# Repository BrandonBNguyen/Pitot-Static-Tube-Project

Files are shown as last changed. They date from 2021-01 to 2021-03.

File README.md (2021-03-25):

# 3D Printed Pitot Static Tube Project

## Introduction

The goal of this project was to design and develop an instrument capable of acquiring accurate measurements of air speed.

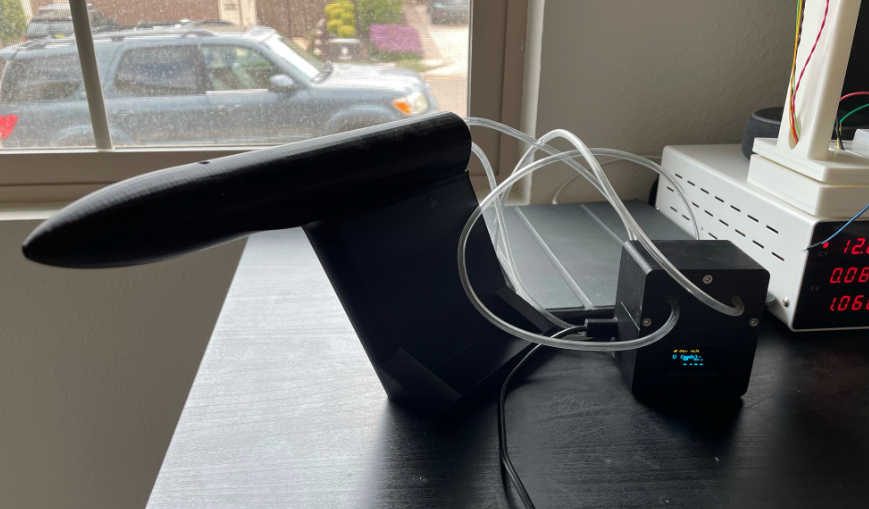
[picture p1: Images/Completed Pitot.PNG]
Completed Pitot Sensor Assembly


## To Do List

 - [x] Select and order components
	 - [x] Pressure sensors ([BMP180](https://www.amazon.com/gp/product/B07Q3PQ81R/ref=ppx_yo_dt_b_search_asin_title?ie=UTF8&psc=1))
	 - [x] Display ([UCTRONICS 0.96 Inch OLED Module](https://www.amazon.com/gp/product/B072Q2X2LL/ref=ppx_yo_dt_b_asin_title_o01_s00?ie=UTF8&psc=1))
	 - [x] Microcontroller ([Teensy LC Board](https://www.pjrc.com/teensy/teensyLC.html))
	 - [x] Nozzle-to-sensor tubing ([4 mm OD pneumatic hose](https://www.amazon.com/gp/product/B07H87S1ZW/ref=ppx_yo_dt_b_asin_title_o06_s00?ie=UTF8&psc=1))
	 - [x] Power source (USB A to microUSB cable)
 - [x] Develop CAD Model
	 - [x] Pitot static tube nozzle assembly
	 - [x] Housing assembly for microcontroller and pressure sensors
 - [x] Test Electronics
	 - [x] Get pressure readings from single BMP 180
	 - [x] Get pressure readings from both BMP 180 sensors simultaneously.
	 - [x] Display pressure measurements and air speed reading to OLED display.
 - [x] Manufacture Components
	 - [x] 3D print nozzle assembly
	 - [x] 3D print housing assembly
	 - [x] Fasten microcontroller, pressure sensors, and OLED display to housing.
	 - [x] Solder and connect wiring.
	 - [x] Connect tubing from nozzle assembly to housing assembly.
	 - [x] Apply sealant to joints and openings in chamber housing pressure sensors.
 - [x] Test and Validate

## Theory

A pitot static tube is an instrument that measures air speed by measuring the pressure at an opening facing directly into the air flow (stagnation pressure), measuring the pressure at an opening perpendicular to the air flow (static pressure), and using the difference in pressure between the two to calculate air speed via Bernoulli's equation.

Pitot-Static Tube

The pitot static tube will be tested to measure air speed from a moving car. The density used in the Bernoulli equation from the above diagram will be calculated from pressure and temperature measurements taken from a stationary position.

## Part Selection

### Sensor Selection

The BMP180 barometric pressure and temperature sensor module was selected to record the differences in pressure between the stagnation pressure and static pressure.

BMP180 Sensors

With a resolution up to 0.03 hPa (3 Pa), the anticipated accuracy of using this sensor to measure air speed is within 2.2 m/s (4.9 mph).

Sensor Accuracy Equation

### Microcontroller Selection

Initial tests to acquire measurements from both BMP180 sensors using an Arduino Uno were unsuccessful due to the sensors sharing the same I2C address. The ability to measure from both sensors and thus record a pressure difference between stagnation and static pressure would require either the use of a multiplexer or a microcontroller with multiple I2C buses. To reduce the number of components used, saving on space and work required to assemble, the latter solution was chosen and the Teensy LC microcontroller board was selected.

### Display

To display the recorded pressure difference and resulting air speed measured from the pitot static tube, the UCTRONICS OLED Module 12864 was selected.

UCTRONICS OLED Module 12864

## CAD Model

### Nozzle Assembly

The nozzle assembly is designed to be clamped to the roof or out of the window of a car and consists of two parts: the main nozzle and the support.

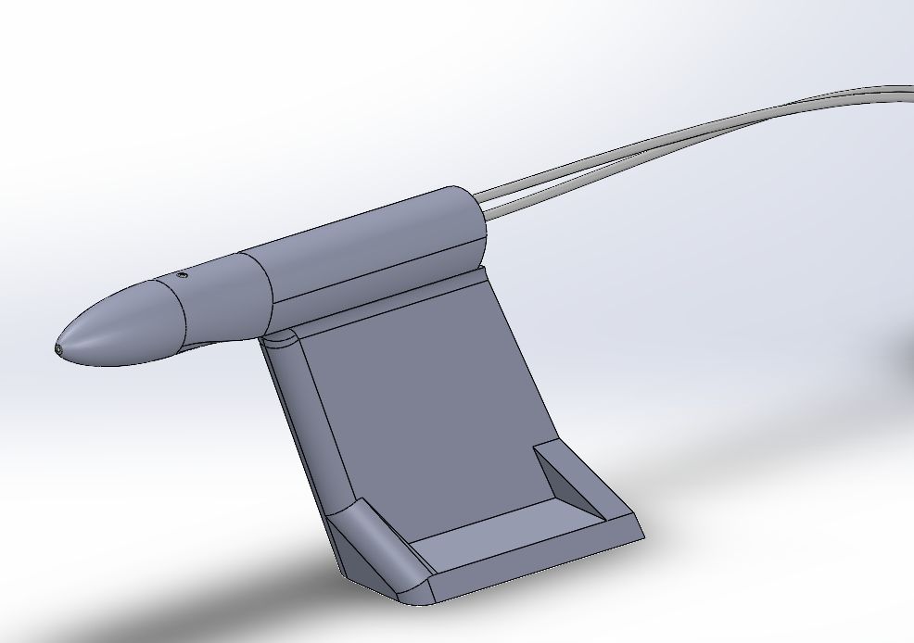
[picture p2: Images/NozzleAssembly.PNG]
Nozzle Assembly


*Nozzle assembly featuring tubing running to pressure sensor chambers.*

#### Nozzle

The main nozzle has a hole in the front which will be connected to a pressure sensor chamber to measure stagnation pressure, and has a hole on the top which will be connected to a separate pressure sensor chamber to measure static pressure. The underside of the nozzle features a dovetail cutout for a rail from the support to be slotted into.

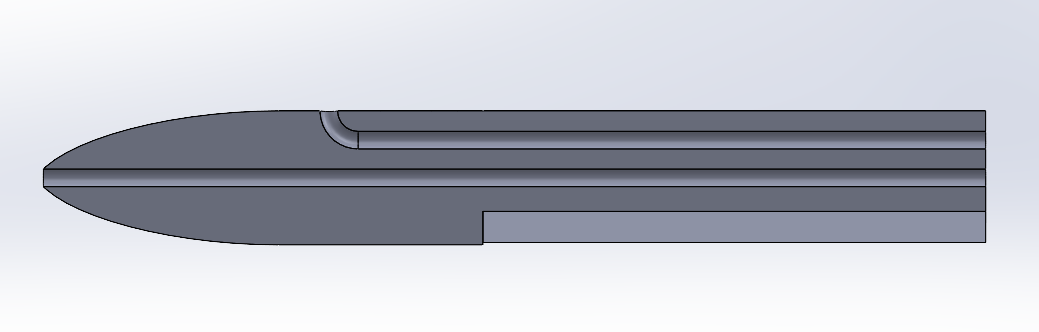
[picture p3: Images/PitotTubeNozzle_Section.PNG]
Section View


*Section view of the nozzle showing internal paths to the front and top of the nozzle to measure stagnation pressure and static pressure, respectively.*

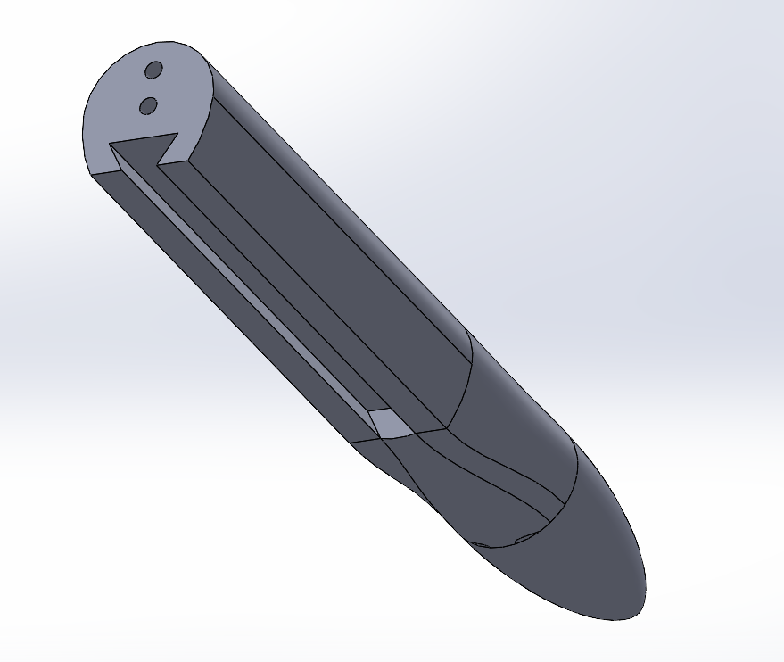
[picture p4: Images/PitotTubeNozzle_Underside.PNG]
Underside View


*Underside view of the nozzle showing the dovetail slot to connect to the support.*

#### Support

The support features a dovetail at one end and a flat edge on the other for which to connect a clamp to hold the entire assembly in place. The support is designed in this way to place the nozzle far out in front and away from the vehicle to ensure that the instrument is not measuring reduced air speeds due to air being slowed by the boundary layer of the vehicle.

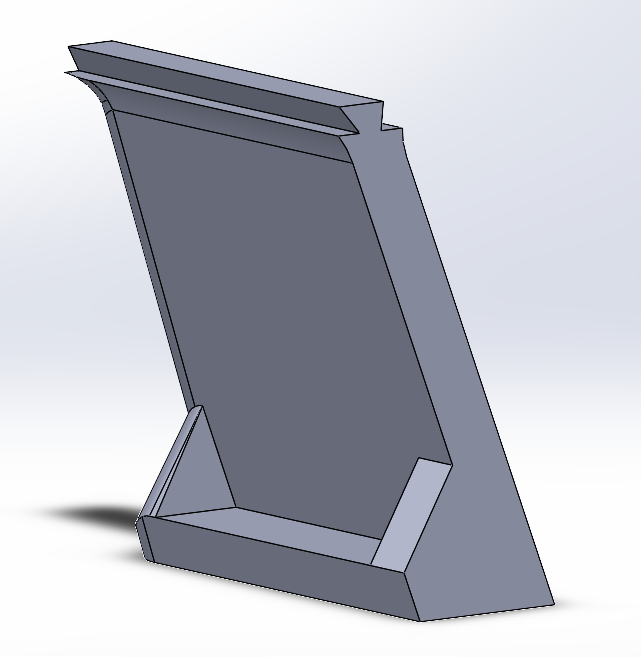
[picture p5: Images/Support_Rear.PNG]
Support rear view


*Rear view of the support showing the dovetail rail on top and the flat edge on the bottom to be clamped.*

### Sensor and Board Housing

#### Initial Design

This initial design for the sensor and board housing was designed for using an Arduino Uno to measure and record readings from the BMP180 sensors and display them via serial output to a computer. Each BMP180 sensor would be housed in its own chamber with wiring passing through a wall between the chamber and the compartment holding the Arduino Uno. A lid with a hole for tubing to each chamber would be fastened to enclose the pressure sensor chambers. Silicone sealant would be used on the wall holding the wiring and between the lid and the housing to ensure an air tight seal for accurate pressure measurements from the two points on the nozzle.

 The CAD design for this was created before tests showed that the Arduino Uno would not be suitable for measuring from both sensors simultaneously. **Lesson learned: ensure that all electronic components work together as expected before designing custom parts for those components.** 

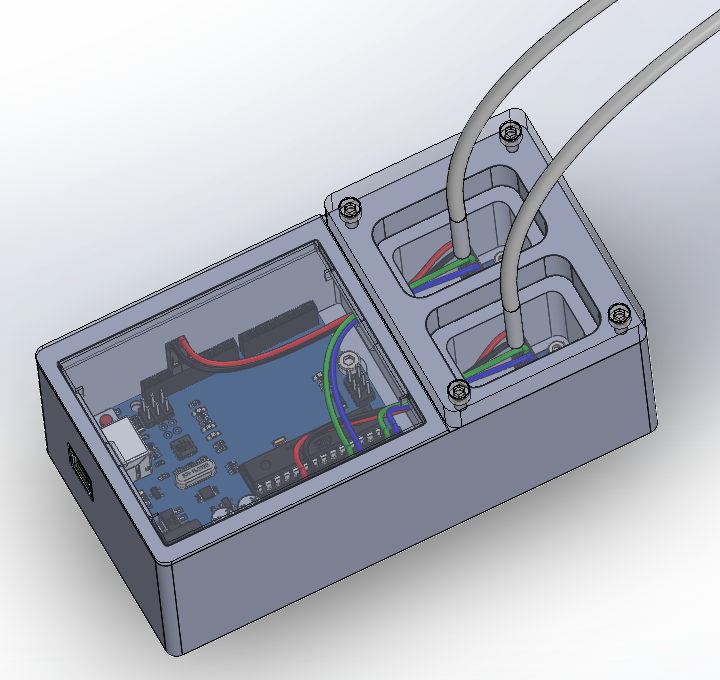
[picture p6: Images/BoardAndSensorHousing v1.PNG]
Initial Board and Sensor Housing Design


#### Final Design

The final design features the Teensy LC microcontroller on one side of the housing and the two BMP180 pressure sensors, each in their own housing, on the other side. The lid to cover the microcontroller is embedded with the outward facing OLED display to show the calculated airspeed result from the pressure difference.

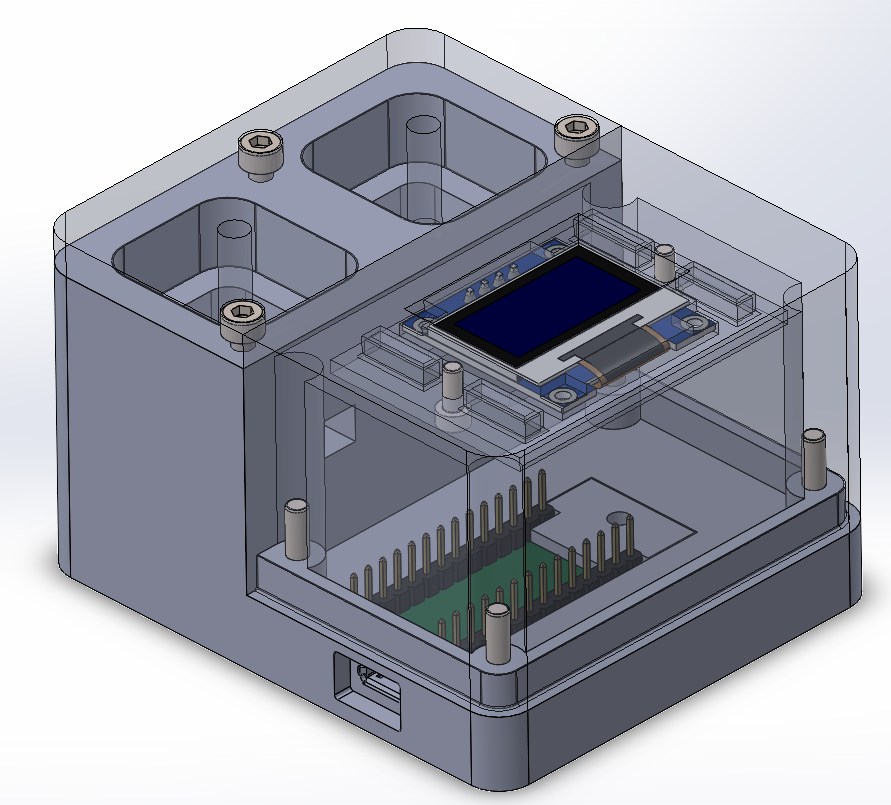
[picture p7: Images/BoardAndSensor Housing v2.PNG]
Final Board and Sensor Housing Design


## Manufacturing

### Nozzle Assembly

The nozzle was printed using black PLA at 210°C with a bed temperature of 60°C. The first attempt at printing the nozzle failed when the print became separated from the build plate. This was likely due to the nozzle being a tall, thin structure with little surface area on the first layer to hold the print in place. The movement of the build plate back and forth along the Y axis and/or friction between nozzle and part likely induced stress on the first layer that lead to separation.

Failed nozzle print attempt

The second attempt at printing the nozzle was printed with a raft, greatly increasing the surface area between the part and the build plate and reducing stresses on the first layer due to movement or friction with the nozzle. This resulted in a successful print.

The nozzle support was printed successfully on the first attempt. The rail fit onto the slot in the nozzle with a snug fit.

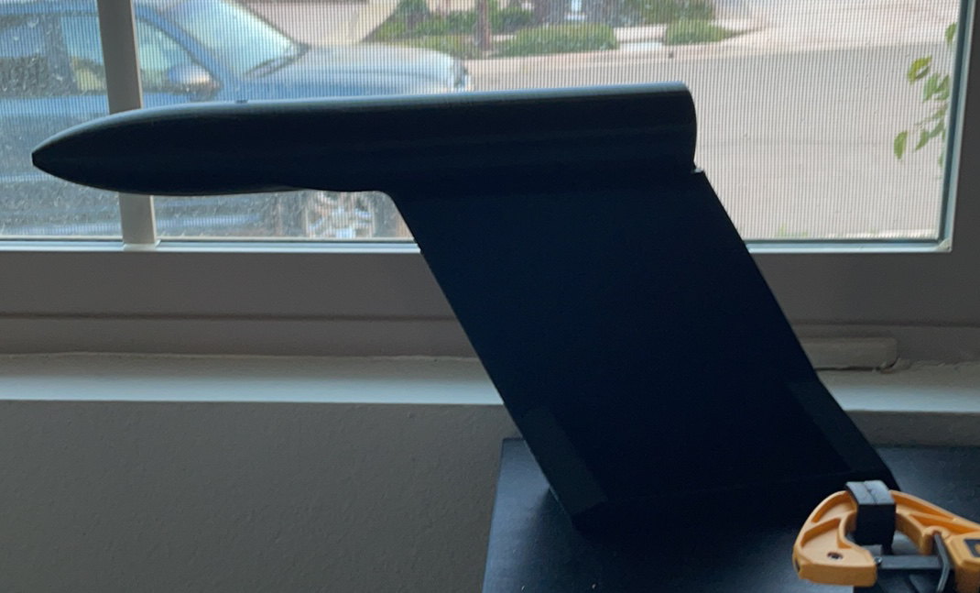
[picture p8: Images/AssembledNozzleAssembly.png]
Printed nozzle assembly


## Testing and Technical Challenges

### Shared I2C Address

A major technical problem that arose while testing the sensors was the fact that the sensors share the same I2C address. An attempted solution involved using the Arduino Uno's hardware I2C bus to measure the result from one sensor and a software I2C bus to measure the result from the other, although implementation of this solution was unsuccessful. Another solution considered was using a multiplexer to facilitate the communication between the Arduino and devices sharing I2C addresses, although this would require additional space in the housing for another component. The solution reached was to use a microcontroller that has two I2C buses such that each sensor would be on a separate I2C bus.

### Measuring from 2 BMP180 Sensors

The [SparkFun BMP180](https://github.com/sparkfun/BMP180_Breakout_Arduino_Library) library was designed to read the pressure and temperature from a single BMP180 sensor on the default I2C bus. To measure the pressure from 2 BMP180 sensors, one on the default I2C bus and the other on the second, the library had to be modified to use the `i2c_t3.h` library instead of the `Wire.h` library. Then, that library was duplicated and modified to use `Wire1` instead of `Wire` to access the BMP180 sensor on the second I2C bus. One library with the original `Wire` was used to measure the pressure from the sensor on the default I2C bus and the other with `Wire1` was used to measure the sensor on the secondary I2C bus.

### Integrating SSD1306 OLED Panel

The [Adafruit SSD1306 library](https://github.com/adafruit/Adafruit_SSD1306), [GFX library](https://github.com/adafruit/Adafruit-GFX-Library), and [BusIO library](https://github.com/adafruit/Adafruit_BusIO) were used to display text and readings to the OLED display. Since the `i2c_t3.h` library was being used to measure the pressure from the sensors, `Wire.h` could not be used to display text and readings and the above libraries had to be changed to use the `i2c_t3.h` library instead of `Wire.h`. Additionally, all instances of `TwoWire` had to be changed to `i2c_t3`.

Successful test showing calculated airspeed displayed on panel from pressure sensors.

## Attributes

The links to the pre-made models used in the CAD made for this project are linked below.

 - [BMP180 Board](https://grabcad.com/library/bmp180-3) by Karolina Seth
 - [Arduino Uno R3 Board](https://grabcad.com/library/arduino-uno-r3-1) by Andrew Whitham
 - [Teensy LC Board](https://grabcad.com/library/teensy-lc-1) by Aron Rubin
 - [SSD1306 OLED Display](https://grabcad.com/library/display-oled-ssd1306-de-0-96-1) by UNIT ELECTRONICS

## Skills Demonstrated

 - Demonstrated strong computer-aided design skills using SolidWorks in working with multiple parts in assemblies and designing custom parts for electronic components.
 - Demonstrated ability to troubleshoot.
	 - Identified cause for failure of a part to print successfully and implemented  solution to increase build plate adhesion.
	 - Identified issue with measuring from multiple sensors that share the same I2C address and identified multiple solutions before implementing the best one.
 - Demonstrated knowledge of C++ and applied it to use a microcontroller to read sensor data and display information using I2C protocol.

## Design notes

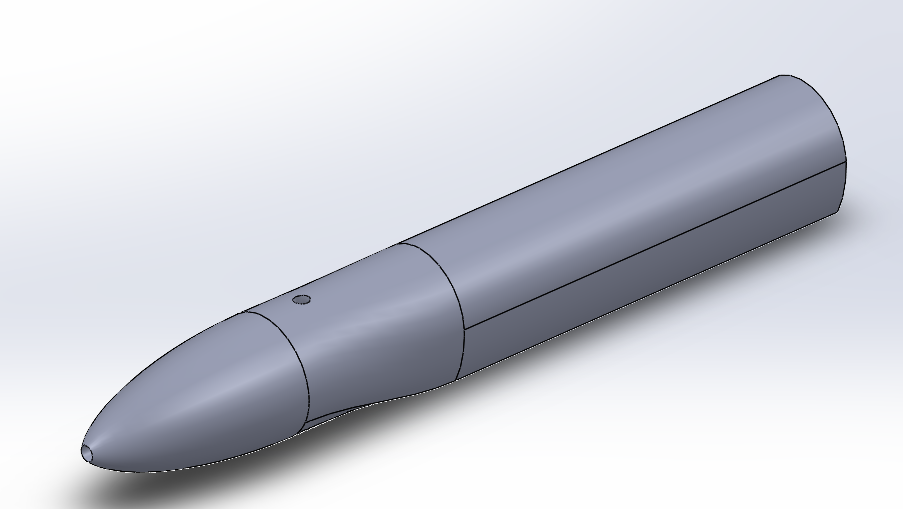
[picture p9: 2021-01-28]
Images/PitotTubeNozzle_Angled.PNG

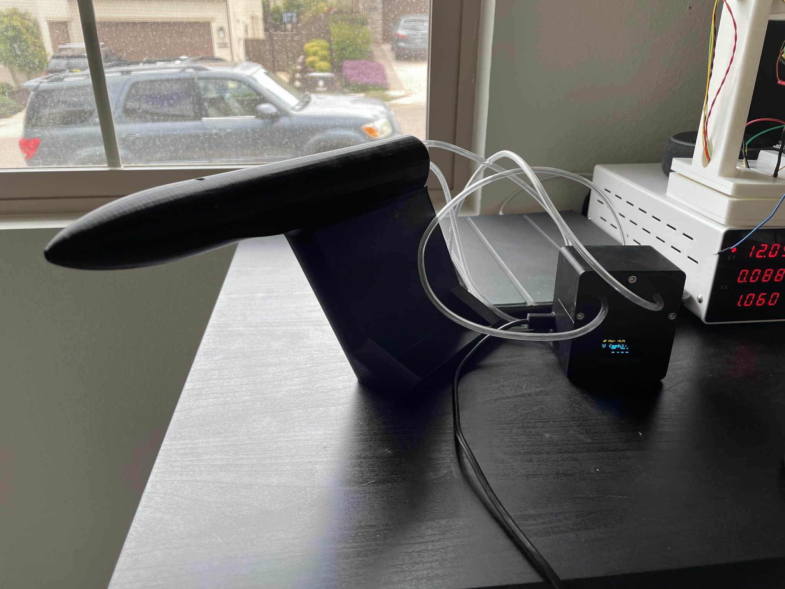
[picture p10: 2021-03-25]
Images/Completed Pitot.jpeg

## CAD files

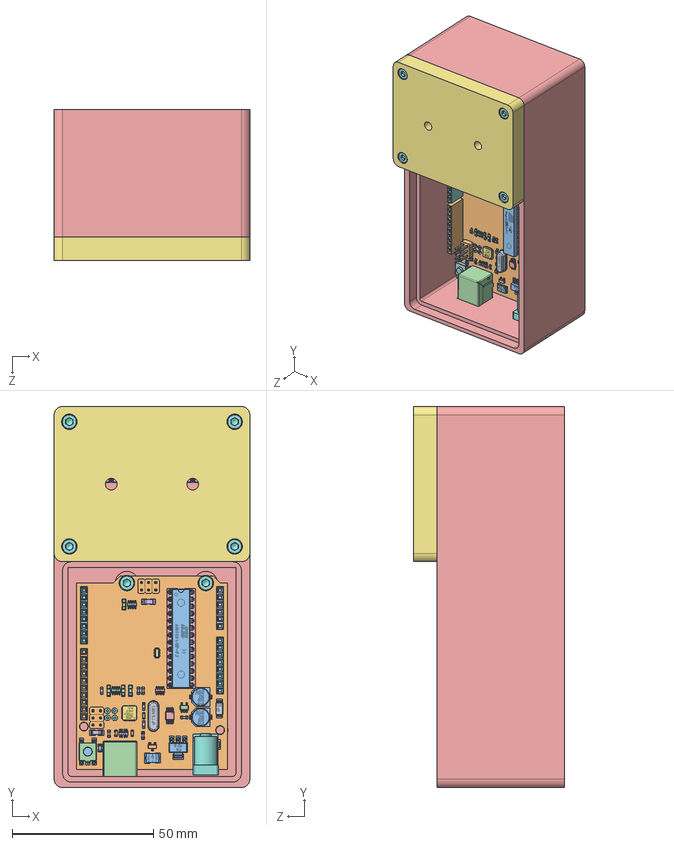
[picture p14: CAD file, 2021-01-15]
Arduino Uno R3 Model/Pressure Sensor Housing.SLDASM
69.3 x 134.9 x 53.3 mm
bmp180 x 2
unoboard blue
47uf CAP Dcase x 2
USB SHELL
USB core
usb top contact x 2
usb btm contact x 2
power jack
crystal
2pin_header__02 x 6
nano - reg
led x 4
dip28
dip socket pin x 28
atmega16u2
8 PORT HEADER x 2
6 PORT HEADER
10 PORT HEADER
ATMEL328P
102 RESISTOR PACK x 2
103 RESISTOR PACK
220 RESISTOR PACK
16mhz crystal - measured
PADS001
603 cap on pad x 8
ssot3
mf-msmf050-2
lmv358
lp2985dgkr
cd1206 diode x 2
603 resistor
blm21
m7 diode
MLC0603 x 2
RESET CORE
RESET
Part7^Pressure Sensor Housing
Pin Connector x 8
Part1^Pressure Sensor Housing
socket head cap screw_am x 8

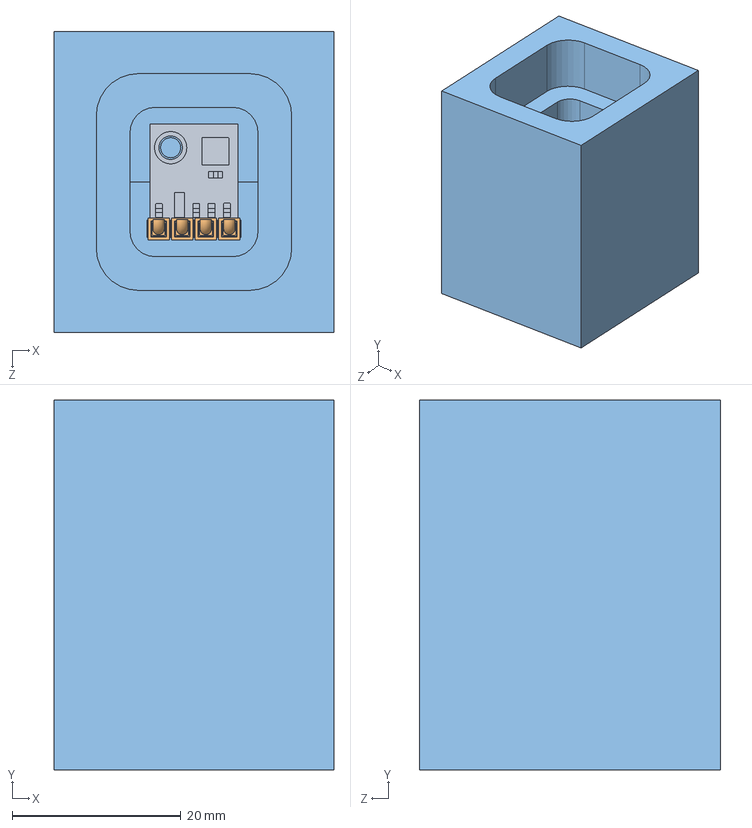
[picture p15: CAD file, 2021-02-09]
CAD/BMP180 Housing.SLDASM
33.2 x 43.9 x 35.7 mm
bmp180
Pin Connector x 4
Part2^BMP180 Housing

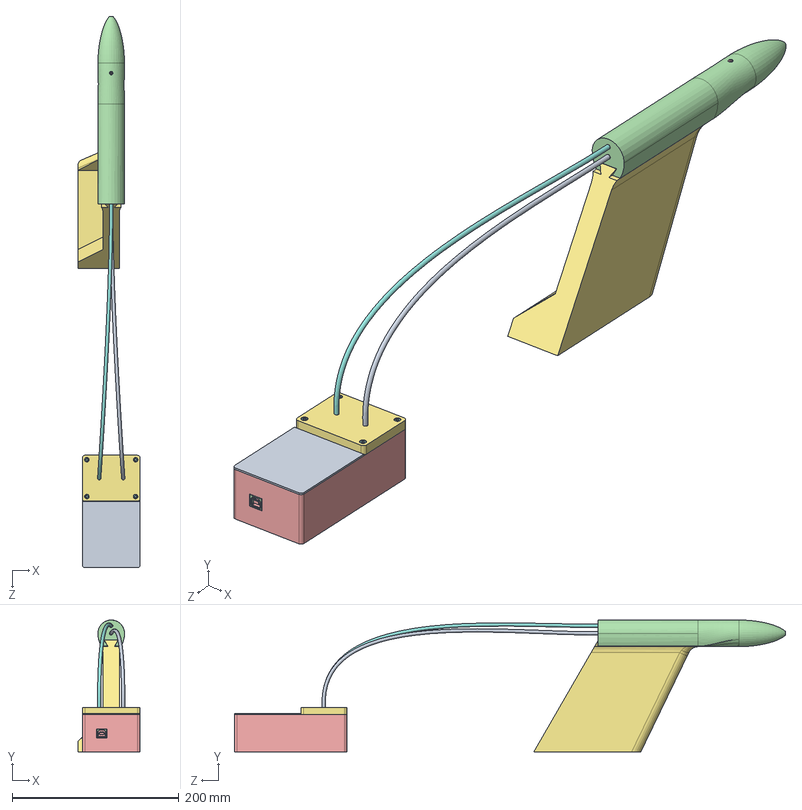
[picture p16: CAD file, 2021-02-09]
CAD/Version 1/01 Pitot Static Tube Full Assembly.SLDASM
74.7 x 158.4 x 661.6 mm
bmp180 x 2
unoboard blue
47uf CAP Dcase x 2
USB SHELL
USB core
usb top contact x 2
usb btm contact x 2
power jack
crystal
2pin_header__02 x 6
nano - reg
led x 4
dip28
dip socket pin x 28
atmega16u2
8 PORT HEADER x 2
6 PORT HEADER
10 PORT HEADER
ATMEL328P
102 RESISTOR PACK x 2
103 RESISTOR PACK
220 RESISTOR PACK
16mhz crystal - measured
PADS001
603 cap on pad x 8
ssot3
mf-msmf050-2
lmv358
lp2985dgkr
cd1206 diode x 2
603 resistor
blm21
m7 diode
MLC0603 x 2
RESET CORE
RESET
Pressure Sensor Housing
Pin Connector x 8
Part1^Pressure Sensor Housing
socket head cap screw_am x 8
Part2^Pressure Sensor Housing
Pin Connector Male x 8
Part3^Pressure Sensor Housing
Part5^Pressure Sensor Housing
Part6^Pressure Sensor Housing
Part8^Pressure Sensor Housing
Part9^Pressure Sensor Housing
Part10^Pressure Sensor Housing
Part11^Pressure Sensor Housing
Part12^Pressure Sensor Housing
Part4^Pressure Sensor Housing
Nozzle^Pitot Nozzle Assembly
Static Pressure Tube^Pitot Nozzle Assembly
Stagnation Pressure Tube^Pitot Nozzle Assembly
Nozzle Mount^Pitot Nozzle Assembly
Part6^01 Pitot Static Tube Full Assembly
Part7^01 Pitot Static Tube Full Assembly

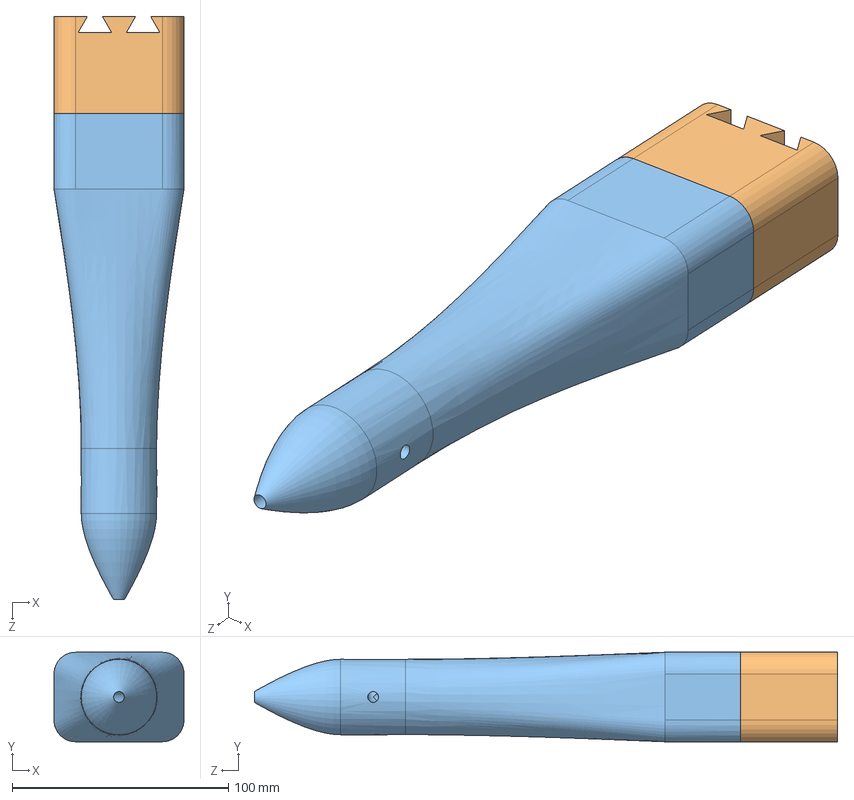
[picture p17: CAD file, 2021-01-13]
Pitot Static Tube.SLDASM
60.2 x 41.4 x 270.0 mm
bmp180 x 2
Part2^Pitot Static Tube
Part3^Pitot Static Tube
Pin Connector

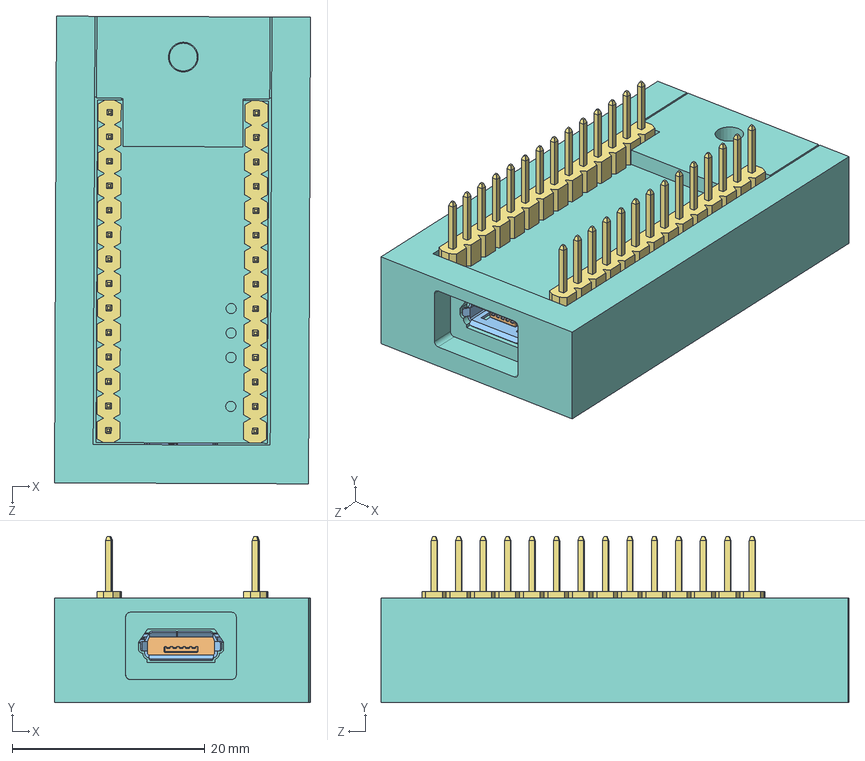
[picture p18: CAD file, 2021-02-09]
CAD/Teensy LC Housing.SLDASM
26.6 x 17.3 x 48.6 mm
Group#12 (1).stp x 5
micro_usb_plastic (1).stp
micro_usb_shell (1).stp
Component21.stp
lead.stp
Component38.stp
Component39.stp
Component40.stp
Component41.stp
Component43.stp
Component44.stp
Component45.stp
Component46.stp
package.stp
lead (1).stp
board.stp
diode_0402 v1.stp x 4
cap0603_03 v3.stp x 2
qfn48 v2.stp
cap0402 v2.stp x 6
resistor_0805 v2.stp
smt_led_0603 v2.stp
Teensy Pin Headers^Teensy LC Housing

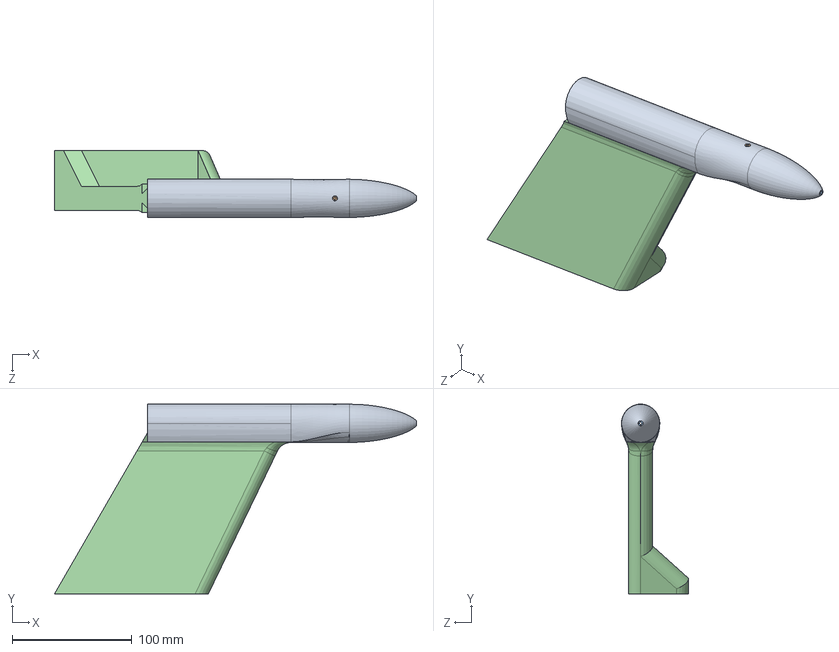
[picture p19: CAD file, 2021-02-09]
CAD/02 Pitot Nozzle Assembly.SLDASM
302.4 x 158.4 x 56.0 mm
Nozzle^Pitot Nozzle Assembly
Static Pressure Tube^Pitot Nozzle Assembly
Stagnation Pressure Tube^Pitot Nozzle Assembly
Nozzle Mount^Pitot Nozzle Assembly

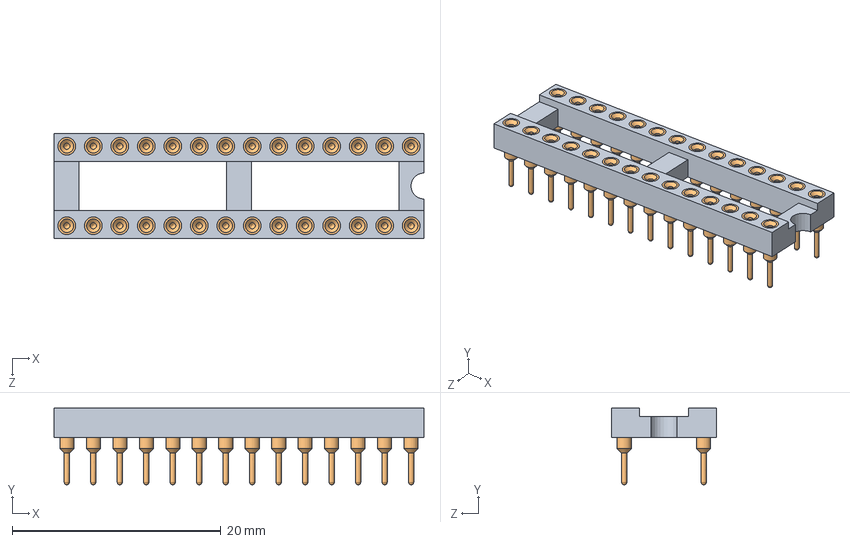
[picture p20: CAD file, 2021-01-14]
CAD/Arduino Uno R3 Model/dip28.SLDASM
35.5 x 7.37 x 10.1 mm
dip28
dip socket pin x 28

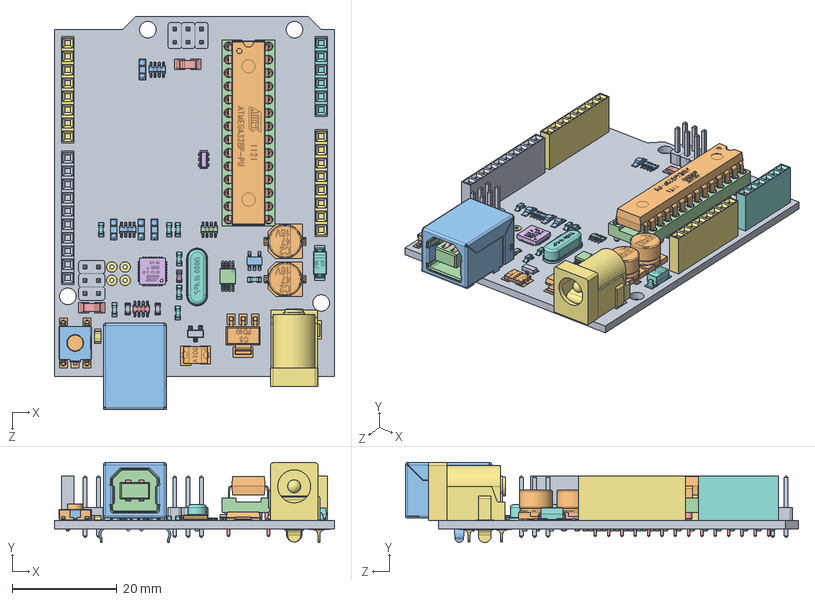
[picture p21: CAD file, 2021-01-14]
CAD/Arduino Uno R3 Model/arduino uno.SLDASM
53.3 x 15.2 x 74.9 mm
unoboard blue
47uf CAP Dcase x 2
USB SHELL
USB core
usb top contact x 2
usb btm contact x 2
power jack
crystal
2pin_header__02 x 6
nano - reg
led x 4
dip28
dip socket pin x 28
atmega16u2
8 PORT HEADER x 2
6 PORT HEADER
10 PORT HEADER
ATMEL328P
102 RESISTOR PACK x 2
103 RESISTOR PACK
220 RESISTOR PACK
16mhz crystal - measured
PADS001
603 cap on pad x 8
ssot3
mf-msmf050-2
lmv358
lp2985dgkr
cd1206 diode x 2
603 resistor
blm21
m7 diode
MLC0603 x 2
RESET CORE
RESET

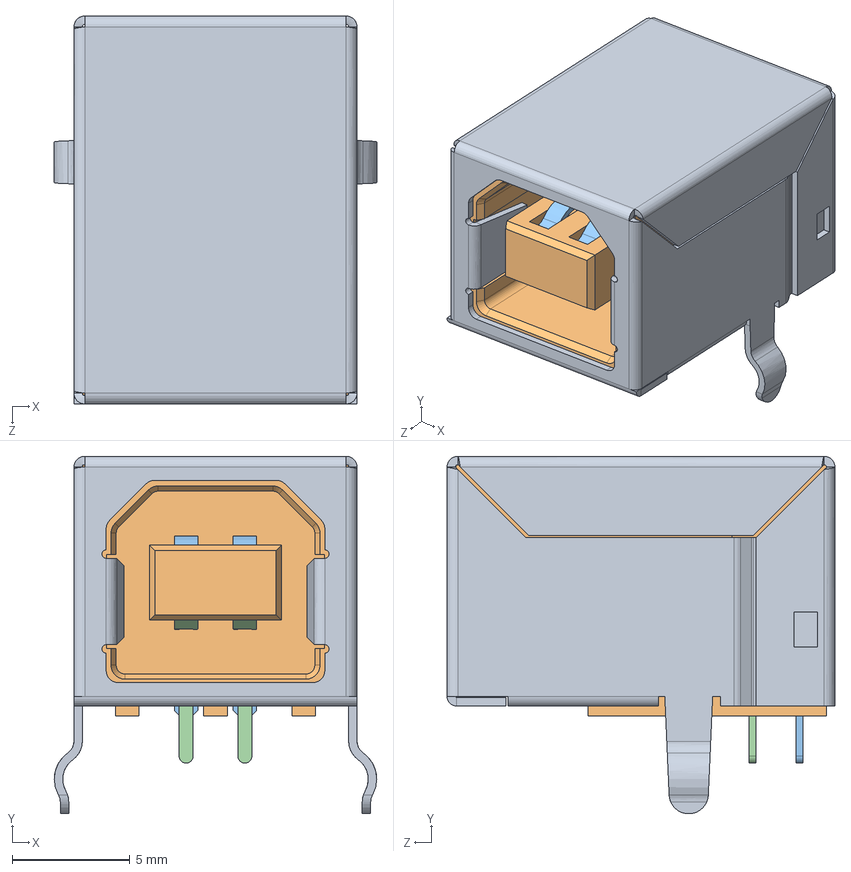
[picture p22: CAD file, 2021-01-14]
CAD/Arduino Uno R3 Model/USB type b.SLDPRT.SLDASM
13.7 x 15.2 x 16.5 mm
USB SHELL
USB core
usb top contact x 2
usb btm contact x 2

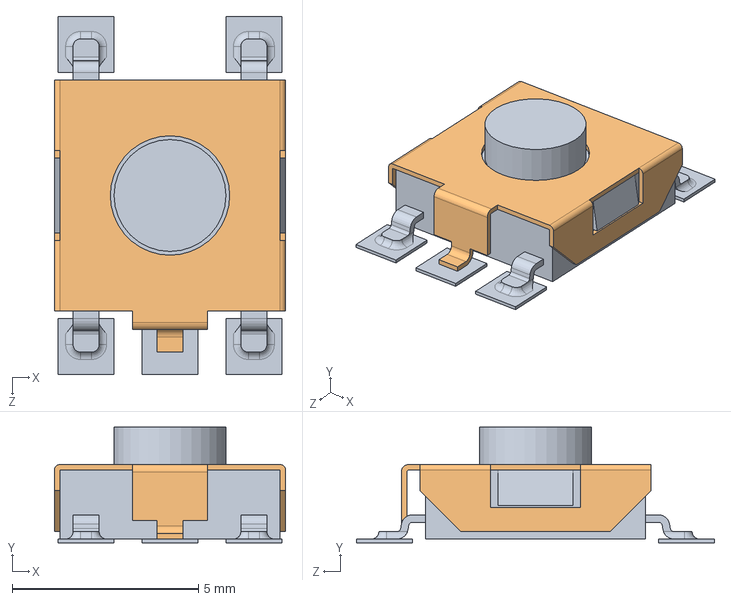
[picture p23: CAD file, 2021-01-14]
CAD/Arduino Uno R3 Model/RESET BUTTON.SLDASM
6.20 x 3.10 x 9.60 mm
RESET CORE
RESET

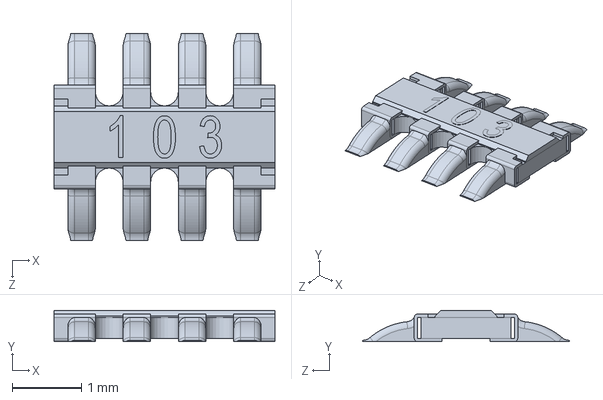
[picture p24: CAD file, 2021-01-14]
CAD/Arduino Uno R3 Model/103 RESISTOR PACK.SLDPRT
3.20 x 0.455 x 3.00 mm

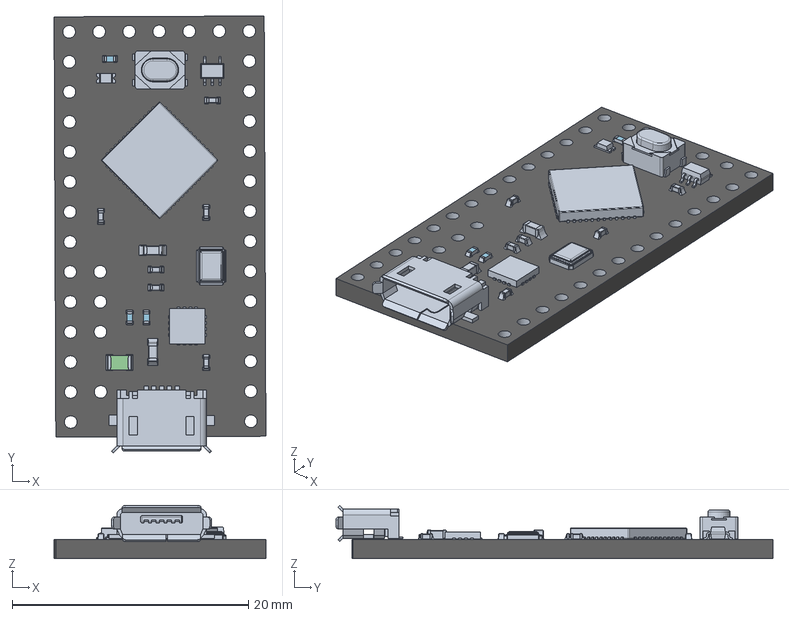
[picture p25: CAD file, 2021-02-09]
CAD/Teensy LC Model/Teensy_lc.stp
17.9 x 37.0 x 4.49 mm
board
micro_usb_plastic (1)
micro_usb_shell (1)
lead
diode_0402 v1 x 4
cap0603_03 v3 x 2
qfn48 v2
cap0402 v2 x 6
resistor_0805 v2
smt_led_0603 v2
package
lead (1)

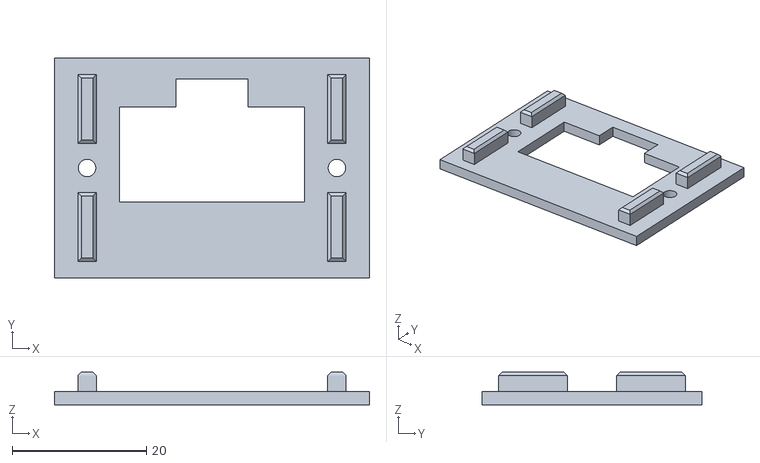
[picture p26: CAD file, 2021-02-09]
Print STL Files/OLED Panel Fastener.STL
46.9 x 32.8 x 4.90

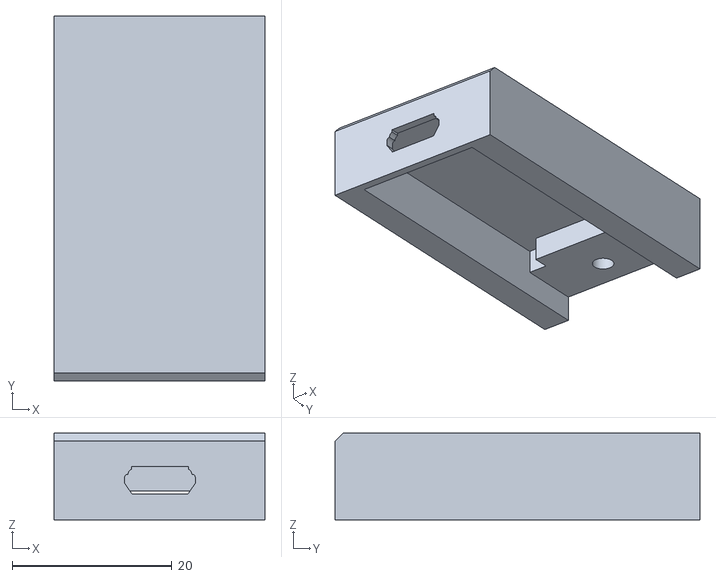
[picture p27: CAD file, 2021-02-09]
Test Prints/Teensy LC Housing.STL
26.4 x 45.7 x 10.9

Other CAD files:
CAD/Arduino Uno R3 Model/603 resistor.SLDPRT
CAD/Version 1/Pressure Sensor Housing.SLDPRT
Print STL Files/Pressure Sensor Housing Lid.STL
Test Prints/Teensy LC Lid.STL
CAD/Arduino Uno R3 Model/10 PORT HEADER.SLDPRT
CAD/Arduino Uno R3 Model/102 RESISTOR PACK.SLDPRT
CAD/Arduino Uno R3 Model/16mhz crystal - measured.SLDPRT
CAD/Arduino Uno R3 Model/220 RESISTOR PACK.SLDPRT
CAD/Arduino Uno R3 Model/2pin_header__02.sldprt
CAD/Arduino Uno R3 Model/47uf CAP Dcase.SLDPRT
CAD/Arduino Uno R3 Model/6 PORT HEADER.SLDPRT
CAD/Arduino Uno R3 Model/603 cap on pad.SLDPRT
CAD/Arduino Uno R3 Model/8 PORT HEADER.SLDPRT
CAD/Arduino Uno R3 Model/ATMEL328P.SLDPRT
CAD/Arduino Uno R3 Model/MLC0603.SLDPRT
CAD/Arduino Uno R3 Model/PADS001.SLDPRT
CAD/Arduino Uno R3 Model/RESET CORE.SLDPRT
CAD/Arduino Uno R3 Model/RESET.SLDPRT
CAD/Arduino Uno R3 Model/USB SHELL.SLDPRT
CAD/Arduino Uno R3 Model/USB core.SLDPRT
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

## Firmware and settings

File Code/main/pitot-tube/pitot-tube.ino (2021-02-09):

// Includes and definitions for SSD1306 Display.
#include <SPI.h>
#include <i2c_t3.h>
#include <Adafruit_GFX.h>
#include <Adafruit_SSD1306.h>

#define SCREEN_WIDTH 128 // OLED display width, in pixels
#define SCREEN_HEIGHT 64 // OLED display height, in pixels

// Declaration for an SSD1306 display connected to I2C (SDA, SCL pins)
// The pins for I2C are defined by the Wire-library. 
// On an arduino UNO:       A4(SDA), A5(SCL)
// On an arduino MEGA 2560: 20(SDA), 21(SCL)
// On an arduino LEONARDO:   2(SDA),  3(SCL), ...
#define OLED_RESET     4 // Reset pin # (or -1 if sharing Arduino reset pin)
#define SCREEN_ADDRESS 0x3C ///< See datasheet for Address; 0x3D for 128x64, 0x3C for 128x32
Adafruit_SSD1306 display(SCREEN_WIDTH, SCREEN_HEIGHT, &Wire, OLED_RESET);

#define NUMFLAKES     10 // Number of snowflakes in the animation example

#define LOGO_HEIGHT   16
#define LOGO_WIDTH    16
static const unsigned char PROGMEM logo_bmp[] =
{ B00000000, B11000000,
  B00000001, B11000000,
  B00000001, B11000000,
  B00000011, B11100000,
  B11110011, B11100000,
  B11111110, B11111000,
  B01111110, B11111111,
  B00110011, B10011111,
  B00011111, B11111100,
  B00001101, B01110000,
  B00011011, B10100000,
  B00111111, B11100000,
  B00111111, B11110000,
  B01111100, B11110000,
  B01110000, B01110000,
  B00000000, B00110000 };

// Includes and definitions for BMP180 sensors.
#include "sensor_read_functions.h"
SFE_BMP180 sensor_1;
SFE_BMP180_2 sensor_2;
float pressure_offset; // Accounts for offset in absolute pressure measurement between the two sensors.

void setup() {
  // Serial.begin(9600);
  // Serial.println("REBOOT");

  // SSD1306_SWITCHCAPVCC = generate display voltage from 3.3V internally
  if(!display.begin(SSD1306_SWITCHCAPVCC, SCREEN_ADDRESS)) {
    // Serial.println(F("SSD1306 allocation failed"));
    for(;;); // Don't proceed, loop forever
  }

  // Clear the buffer
  display.clearDisplay();
  display.setTextSize(1);      // Normal 1:1 pixel scale
  display.setTextColor(SSD1306_WHITE); // Draw white text
  display.setCursor(0, 0);     // Start at top-left corner
  display.cp437(true);         // Use full 256 char 'Code Page 437' font

  display.write("SSD1306 Initialized\n");
  display.display();

  if (sensor_1.begin())
  {
    // Serial.println("Sensor 1 init success");
    display.write("BMP180 1 Initialized\n");
    display.display();
  }
  else
  {
    // Sensor 1 failed to connect.
    // Serial.println("Sensor 1 init fail\n\n");
    display.write("BMP180 1 Initialized\n");
    display.display();
    while(1); // Pause forever.
  }

  if (sensor_2.begin())
  {
    // Serial.println("Sensor 2 init success");
    display.write("BMP180 2 Initialized\n");
    display.display();
  }
  else
  {
    // Sensor 2 failed to connect.
    // Serial.println("Sensor 2 init fail\n\n");
    display.write("BMP180 1 Initialized\n");
    display.display();
    while(1); // Pause forever.
  }

  // Measure the initial difference in pressure (assuming no airspeed) to get pressure sensor offset.
  pressure_offset = get_pressure(sensor_1) - get_pressure(sensor_2);
  display.write("Pressure Difference\nCalibrated");
  display.display();
}

void loop() {
  // Serial.print("Sensor 1 Pressure (mb): ");
  // Serial.println(get_pressure(sensor_1));
  // Serial.print("Sensor 2 Pressure (mb): ");
  // Serial.println(get_pressure(sensor_2));

  // Calculate difference in pressure in pascals.
  float diff_pressure = 100*(get_pressure(sensor_1) - (get_pressure(sensor_2) + pressure_offset));
  float airspeed = sqrt(2 * abs(diff_pressure) / 1.225);

  // Serial.print("Pressure Diff (Pa): ");
  // Serial.println(diff_pressure);
  // Serial.print("Calculated Airspeed (m/s): ");
  // Serial.println(airspeed);
  // Serial.print("Calculated Airspeed (mph): ");
  // Serial.println(airspeed * 2.23694);
  // Serial.println();

  display.clearDisplay();
  display.setCursor(0,0);
  display.print("dP (Pa): ");
  display.println(diff_pressure);
  display.println();
  display.setTextSize(2);
  display.println("V (mph): ");
  display.setTextSize(3);
  if (airspeed * 2.23694 <= 10) {
    display.print("  ");
  } else if (airspeed * 2.23694 <= 100) {
    display.print(" ");
  }
  display.println(airspeed * 2.23694);
  display.setTextSize(1);
  display.display();

  delay(10);
}

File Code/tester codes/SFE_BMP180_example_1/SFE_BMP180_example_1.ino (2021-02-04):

/* SFE_BMP180 library example sketch

This sketch shows how to use the SFE_BMP180 library to read the
Bosch BMP180 barometric pressure sensor.
https://www.sparkfun.com/products/11824

Like most pressure sensors, the BMP180 measures absolute pressure.
This is the actual ambient pressure seen by the device, which will
vary with both altitude and weather.

Before taking a pressure reading you must take a temparture reading.
This is done with startTemperature() and getTemperature().
The result is in degrees C.

Once you have a temperature reading, you can take a pressure reading.
This is done with startPressure() and getPressure().
The result is in millibar (mb) aka hectopascals (hPa).

If you'll be monitoring weather patterns, you will probably want to
remove the effects of altitude. This will produce readings that can
be compared to the published pressure readings from other locations.
To do this, use the sealevel() function. You will need to provide
the known altitude at which the pressure was measured.

If you want to measure altitude, you will need to know the pressure
at a baseline altitude. This can be average sealevel pressure, or
a previous pressure reading at your altitude, in which case
subsequent altitude readings will be + or - the initial baseline.
This is done with the altitude() function.

Hardware connections:

- (GND) to GND
+ (VDD) to 3.3V

(WARNING: do not connect + to 5V or the sensor will be damaged!)

You will also need to connect the I2C pins (SCL and SDA) to your
Arduino. The pins are different on different Arduinos:

Any Arduino pins labeled:  SDA  SCL
Uno, Redboard, Pro:        A4   A5
Mega2560, Due:             20   21
Leonardo:                   2    3

Leave the IO (VDDIO) pin unconnected. This pin is for connecting
the BMP180 to systems with lower logic levels such as 1.8V

Have fun! -Your friends at SparkFun.

The SFE_BMP180 library uses floating-point equations developed by the
Weather Station Data Logger project: http://wmrx00.sourceforge.net/

Our example code uses the "beerware" license. You can do anything
you like with this code. No really, anything. If you find it useful,
buy me a beer someday.

V10 Mike Grusin, SparkFun Electronics 10/24/2013
V1.1.2 Updates for Arduino 1.6.4 5/2015
*/

// Your sketch must #include this library, and the Wire library.
// (Wire is a standard library included with Arduino.):

#include <SFE_BMP180_2.h>
#include <i2c_t3.h>

// You will need to create an SFE_BMP180 object, here called "pressure":

SFE_BMP180_2 pressure;

#define ALTITUDE 1655.0 // Altitude of SparkFun's HQ in Boulder, CO. in meters

void setup()
{
  Serial.begin(9600);
  Serial.println("REBOOT");

  // Initialize the sensor (it is important to get calibration values stored on the device).

  if (pressure.begin())
    Serial.println("BMP180 init success");
  else
  {
    // Oops, something went wrong, this is usually a connection problem,
    // see the comments at the top of this sketch for the proper connections.

    Serial.println("BMP180 init fail\n\n");
    while(1); // Pause forever.
  }
}

void loop()
{
  char status;
  double T,P,p0,a;

  // Loop here getting pressure readings every 10 seconds.

  // If you want sea-level-compensated pressure, as used in weather reports,
  // you will need to know the altitude at which your measurements are taken.
  // We're using a constant called ALTITUDE in this sketch:
  
  Serial.println();
  Serial.print("provided altitude: ");
  Serial.print(ALTITUDE,0);
  Serial.print(" meters, ");
  Serial.print(ALTITUDE*3.28084,0);
  Serial.println(" feet");
  
  // If you want to measure altitude, and not pressure, you will instead need
  // to provide a known baseline pressure. This is shown at the end of the sketch.

  // You must first get a temperature measurement to perform a pressure reading.
  
  // Start a temperature measurement:
  // If request is successful, the number of ms to wait is returned.
  // If request is unsuccessful, 0 is returned.

  status = pressure.startTemperature();
  if (status != 0)
  {
    // Wait for the measurement to complete:
    delay(status);

    // Retrieve the completed temperature measurement:
    // Note that the measurement is stored in the variable T.
    // Function returns 1 if successful, 0 if failure.

    status = pressure.getTemperature(T);
    if (status != 0)
    {
      // Print out the measurement:
      Serial.print("temperature: ");
      Serial.print(T,2);
      Serial.print(" deg C, ");
      Serial.print((9.0/5.0)*T+32.0,2);
      Serial.println(" deg F");
      
      // Start a pressure measurement:
      // The parameter is the oversampling setting, from 0 to 3 (highest res, longest wait).
      // If request is successful, the number of ms to wait is returned.
      // If request is unsuccessful, 0 is returned.

      status = pressure.startPressure(3);
      if (status != 0)
      {
        // Wait for the measurement to complete:
        delay(status);

        // Retrieve the completed pressure measurement:
        // Note that the measurement is stored in the variable P.
        // Note also that the function requires the previous temperature measurement (T).
        // (If temperature is stable, you can do one temperature measurement for a number of pressure measurements.)
        // Function returns 1 if successful, 0 if failure.

        status = pressure.getPressure(P,T);
        if (status != 0)
        {
          // Print out the measurement:
          Serial.print("absolute pressure: ");
          Serial.print(P,2);
          Serial.print(" mb, ");
          Serial.print(P*0.0295333727,2);
          Serial.println(" inHg");

          // The pressure sensor returns abolute pressure, which varies with altitude.
          // To remove the effects of altitude, use the sealevel function and your current altitude.
          // This number is commonly used in weather reports.
          // Parameters: P = absolute pressure in mb, ALTITUDE = current altitude in m.
          // Result: p0 = sea-level compensated pressure in mb

          p0 = pressure.sealevel(P,ALTITUDE); // we're at 1655 meters (Boulder, CO)
          Serial.print("relative (sea-level) pressure: ");
          Serial.print(p0,2);
          Serial.print(" mb, ");
          Serial.print(p0*0.0295333727,2);
          Serial.println(" inHg");

          // On the other hand, if you want to determine your altitude from the pressure reading,
          // use the altitude function along with a baseline pressure (sea-level or other).
          // Parameters: P = absolute pressure in mb, p0 = baseline pressure in mb.
          // Result: a = altitude in m.
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

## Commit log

2021-01-13 BMP180 Chamber Resize
    Resized the chambers containing each BMP180 pressure module to make them narrower, requiring less time and material to manufacture.
    [Pitot Static Tube.SLDASM]
2021-01-13 Chamber adjustment.
    Made the chambers shorter to further conserve materials and added holes to the back for wiring.
    [Pitot Static Tube.SLDASM]
2021-01-13 Puzzle connector
    Added a puzzle connector interface to the back of the piece containing the pressure chambers to allow for connecting a piece to house the Arduino.
    [Pitot Static Tube.SLDASM]
2021-01-13 Arduino casing
    Added arduino casing and holes on it as well as nozzle for attachment of something to attach the pitot tube assembly to the body of a car.
2021-01-14 Version 2
    Created version 2 with separate nozzle assembly and sensor assembly.
    Also updated new Arduino Uno model in color.
    [10 PORT HEADER.SLDPRT, 102 RESISTOR PACK.SLDPRT, 103 RESISTOR PACK.SLDPRT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]
2021-01-15 Electronics Mounting and Pressure Seal Added
    [Pin Connector.SLDPRT, Pitot Static Tube V2.SLDASM, Pressure Sensor Housing.SLDASM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]
2021-01-15 Added snap lid over Arduino and wiring.
    [Pin Connector Male.SLDPRT, Pin Connector.SLDPRT]
2021-01-15 Combined pressure sensors and arduino assembly with nozzle assembly
    [01 Pitot Static Tube Full Assembly.SLDASM, Pitot Nozzle Assembly.SLDASM, Pitot Static Tube V2.SLDASM]
2021-01-28 Added screenshots of nozzle CAD
    [01 Pitot Static Tube Full Assembly.SLDASM, Arduino Housing Lid.STL, Nozzle Support.STL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]
2021-01-29 Create BoardAndSensorHousing v1.PNG
2021-01-29 Moved AssembledNozzleAssembly.png
2021-02-04 Added code to read from both pressure sensors.
2021-02-09 Created CAD V2 of Main Housing
    [BMP180 Housing.SLDASM, BMP180 Housing.STL, OLED Display Fastener.STL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]
2021-02-09 Create BoardAndSensor Housing v2.PNG
2021-02-09 Added M3x8 screw to lid fastening Teensy LC
    [BMP180 Housing.SLDASM, Teensy LC Housing.SLDASM]
2021-02-09 Organized models into CAD folder
    [01 Pitot Static Tube Full Assembly.SLDASM, 02 Pitot Nozzle Assembly.SLDASM, 10 PORT HEADER.SLDPRT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]
2021-02-09 Renamed 'STL Files' folder to 'Print STL Files'
    [Arduino Housing Lid.STL, Nozzle Support.STL, Nozzle.STL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]
2021-02-09 Added M2.5x6 screw for BMP180s
    [BMP180 Housing.SLDASM, Teensy LC Housing.SLDASM]
